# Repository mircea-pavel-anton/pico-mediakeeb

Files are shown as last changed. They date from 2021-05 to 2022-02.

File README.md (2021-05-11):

# pico-mediakeeb

A small multimedia macro-pad implemented on top of the RP2040 based Raspberry pi Pico.

---

## Getting Started

The basic steps to get this up and running are:

- Set up your Raspberry Pi Pico
- Order the PCB from your PCB printing service of choice
- Solder all the components to the PCB
- 3D print a case
- Assemble it all together

### Setting up your Pi

Setting up the Raspberry Pi Pico to function as the brains of this operation is a realtively simple 2-step task.

First things first. We need to flash our Pi with the latest CircuitPython uf2 file so that we can use micropython to program it and gain access to useful adafruit libraries.

You can find the latest CircuitPython.uf2 file as well as a flashing guide [here](https://learn.adafruit.com/getting-started-with-raspberry-pi-pico-circuitpython/circuitpython)

Once you flashed your pico, it should unmount by itself and then remount as a storage device called `CIRCUITPYTHON`. That means you succesfully flashed your pi and are ready to continue.  

Next, we need to download or clone this repo, and copy over the contents of `src/` into the mounted `CIRCUITPYTHON` volume, so thy pi can run it. Once you copied everything over, the pi should start running the code. You can tell whether or not it is working by the onboard LED. Once the program starts running, it should turn on. If it doesn't, try unplugging and replugging your pico.

### Printing your own PCB

| PCB Front | PCB Back |
| :---: | :---: |
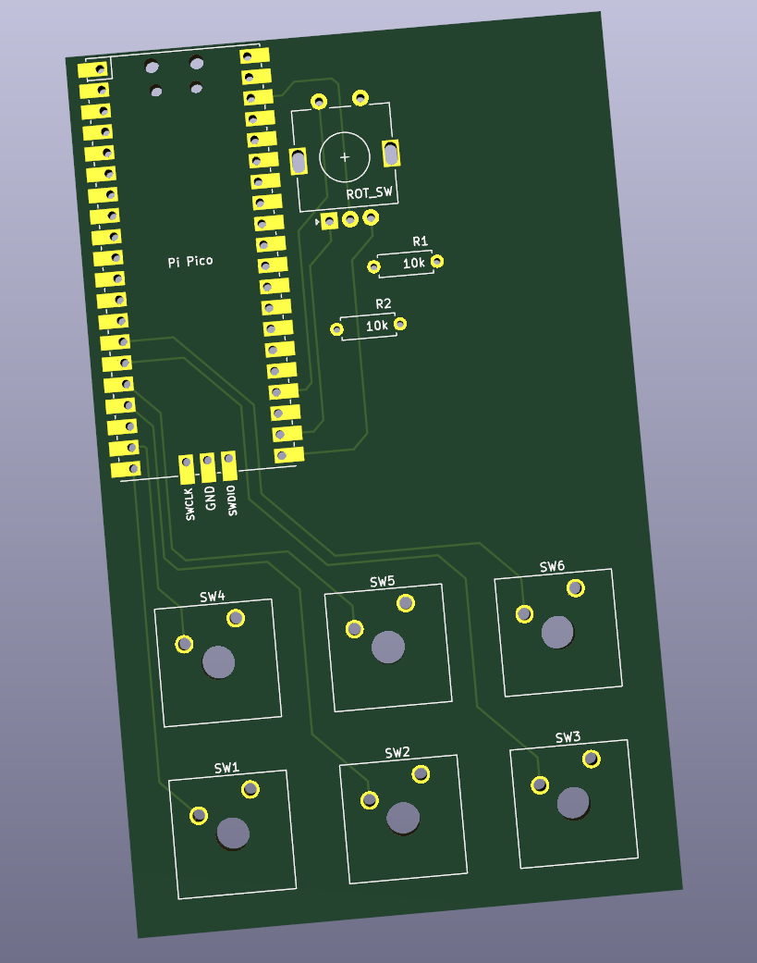
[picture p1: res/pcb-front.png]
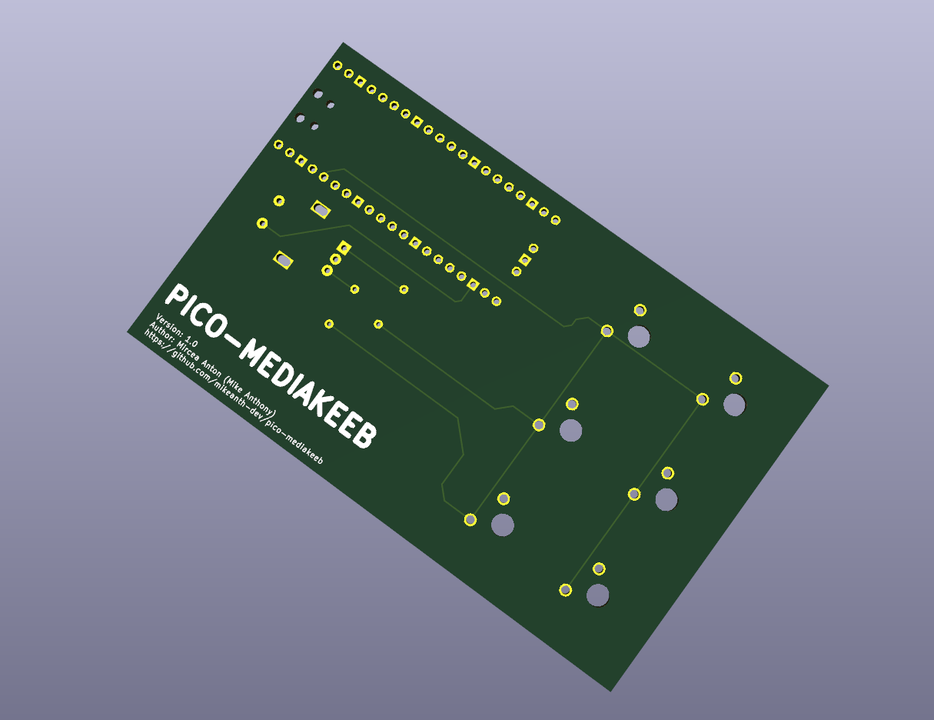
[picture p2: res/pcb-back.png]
|  |  |

In the `pcb/` directory of this repo, you can find a KiCAD project that contains the circuit schematic (in case you want to handwire everything) and a PCB design (in case you want to print your own board). You should open the project and generate the gerber files, or just take the pre-generated ones from `pcb/gerber` and send them to your preffered PCB printing service. I personally used JLC PCB.

### Soldering the components to the PCB

The components you need for this project are the following:

- A raspberry pi Pico
- 2 10k ohm resistors
- a rotary encoder with a switch
- 6 cherry-style keyswitches

All the part names are printed onto the PCB, so you should have no issues in finding out what to solder where.

### 3D printing a case

TODO ...

### Assemble it all together

TODO ...

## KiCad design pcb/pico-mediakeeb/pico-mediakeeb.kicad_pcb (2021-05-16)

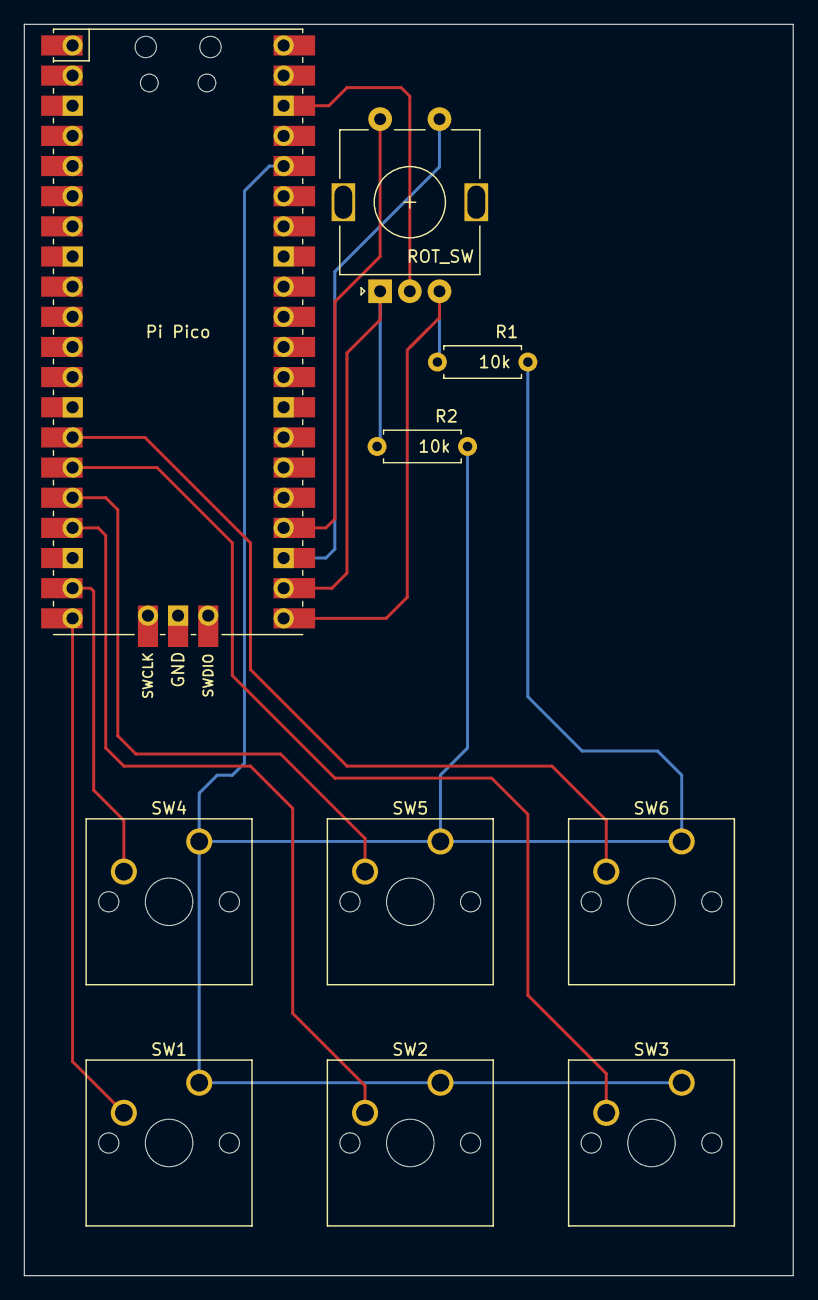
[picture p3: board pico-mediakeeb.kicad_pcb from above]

Board: 2 copper layers, 64.8 x 105.4 mm, 10 parts (0 on the bottom side), 12 nets.

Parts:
Pi Pico: RPi_Pico_SMD_TH
R1, R2: 10k; R_Axial_DIN0207_L6.3mm_D2.5mm_P7.62mm_Horizontal
ROT_SW: Rotary_Encoder_Switch; RotaryEncoder_Alps_EC11E-Switch_Vertical_H20mm
SW1: btn_prev; SW_Cherry_MX_1.00u_PCB
SW2: btn_play_pause; SW_Cherry_MX_1.00u_PCB
SW3: btn_next; SW_Cherry_MX_1.00u_PCB
SW4: btn_macro_1; SW_Cherry_MX_1.00u_PCB
SW5: btn_macro_2; SW_Cherry_MX_1.00u_PCB
SW6: btn_macro_3; SW_Cherry_MX_1.00u_PCB

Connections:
unnamed: Pi Pico.36, R1.1, R2.1, SW1.1, SW2.1, SW3.1, SW4.1, SW5.1, SW6.1
unnamed: Pi Pico.21, R1.2, ROT_SW.B
unnamed: Pi Pico.22, R2.2, ROT_SW.A
unnamed: Pi Pico.20, SW1.2
unnamed: Pi Pico.17, SW2.2
unnamed: Pi Pico.15, SW3.2
unnamed: Pi Pico.19, SW4.2
unnamed: Pi Pico.16, SW5.2
unnamed: Pi Pico.14, SW6.2
unnamed: Pi Pico.38, ROT_SW.C
unnamed: Pi Pico.23, ROT_SW.S1
unnamed: Pi Pico.24, ROT_SW.S2

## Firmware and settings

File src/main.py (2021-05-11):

# ------------ Imports ------------
import board
from button import Button
from led import Led
from encoder import Encoder
from functions import *

# ------------ Track control Buttons ------------
# Previous Track
btn_prev = Button( board.GP15 )
btn_prev.setOnPressCallback( prev_track )

# Play/Pause
btn_plpa = Button( board.GP13 )
btn_plpa.setOnPressCallback( play_pause )

# Next Track
btn_next = Button( board.GP11 )
btn_next.setOnPressCallback( next_track )

# ------------ Colume control ------------
# Volume encoder
vol_encoder = Encoder( board.GP17, board.GP16, board.GP18 )
vol_encoder.setOnRotateCwCallback( volume_up )
vol_encoder.setOnRotateCcwCallback( volume_down )
vol_encoder.setOnPressCallback( mute_toggle )
vol_encoder.setOnReleaseCallback( mute_toggle )

# ------------ Extra Function Keys ------------
# Macro Button #1
btn_mac1 = Button( board.GP14 )
btn_mac1.setOnPressCallback( macro1 )

# Macro Button #2
btn_mac2 = Button( board.GP12 )
btn_mac1.setOnPressCallback( macro1 )

# Macro Button #3
btn_mac3 = Button( board.GP10 )
btn_mac1.setOnPressCallback( macro1 )

# ------------ Status LED ------------
led = Led( board.LED )


led.on()
while True:
    # Track Control Buttons
    btn_prev.onClick()
    btn_plpa.onClick()
    btn_next.onClick()
    
    # Extra Function Keys
    btn_mac1.onClick()
    btn_mac2.onClick()
    btn_mac3.onClick()


    # Volume Control
    vol_encoder.onRotate()
    vol_encoder.onClick()
led.off()

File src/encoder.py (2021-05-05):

import digitalio
from button import Button

class Encoder:
    data = None
    data_old = None
    clock = None
    clock_old = None
    
    onRotateCwCallback = None
    onRotateCcwCallback = None
    
    button = None
    
    def __init__(self, clk_pin, dt_pin, sw_pin):
        self.data = digitalio.DigitalInOut( dt_pin)
        self.data.direction = digitalio.Direction.INPUT
        self.data_old = False

        self.clock = digitalio.DigitalInOut( clk_pin )
        self.clock.direction = digitalio.Direction.INPUT
        self.clock_old = False
        
        self.button = Button( sw_pin, digitalio.Pull.UP )

    def onRotate(self):
        clock_now = self.clock.value
        data_now = self.data.value

        if clock_now != self.clock_old:
            data_now = clock_now ^ data_now
            if data_now:
                if self.onRotateCwCallback is not None:
                    self.onRotateCwCallback()
            else:
                if self.onRotateCcwCallback is not None:
                    self.onRotateCcwCallback()
        self.clock_old = clock_now

    def onClick(self):
        self.button.onClick()

    def setOnRotateCwCallback(self, method):
        self.onRotateCwCallback = method
    
    def setOnRotateCcwCallback(self, method):
        self.onRotateCcwCallback = method
        
    def setOnPressCallback(self, method):
        self.button.onPressCallback = method

    def setOnReleaseCallback(self, method):
        self.button.onReleaseCallback = method

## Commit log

2021-05-04 Rename the pico board to `pico-mediakeeb`
2021-05-04 Add 3 more macro buttons
2021-05-05 Create custom class for buttons
2021-05-05 Create custom class for rotary encoders
2021-05-05 Create custom class for leds
2021-05-05 Create kicad Project
    [pico-mediakeeb.kicad_pcb, pico-mediakeeb.sch]
2021-05-05 Change button pins
2021-05-05 change pin order
2021-05-05 Add circuit schematic
2021-05-05 Make labels more readable
    [pico-mediakeeb.sch]
2021-05-05 Update schematic to use generic rotary encoder
    [pico-mediakeeb.sch]
2021-05-05 Remove unused lib
    [pico-mediakeeb.kicad_pcb]
2021-05-05 Update schematic
    [pico-mediakeeb.sch]
2021-05-05 Auto generate PCB
    [pico-mediakeeb.kicad_pcb]
2021-05-07 Update pcb design
2021-05-11 Reorder buttons to make more sense for the pcb design
    [pico-mediakeeb.sch]
2021-05-11 Implement pcb design v1
    [pico-mediakeeb.kicad_pcb]
2021-05-11 Update code to reflect button pin changes
2021-05-11 Upload PCB screenshots
2021-05-11 Add pcb screenshots
2021-05-11 Add gerber files
    [pico-mediakeeb-B_Cu.gbl, pico-mediakeeb-B_Mask.gbs, pico-mediakeeb-B_SilkS.gbo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]
2021-05-16 Update pcb traces and add JLC order number placeholder
    [pico-mediakeeb.kicad_pcb]
2021-05-16 Update gerber files
    [pico-mediakeeb-B_Cu.gbr, pico-mediakeeb-B_Mask.gbr, pico-mediakeeb-B_Paste.gbr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]
2022-02-01 [ImgBot] Optimize images (#1)
    *Total -- 198.81kb -> 119.53kb (39.87%)
    /res/pcb-back.png -- 92.08kb -> 51.34kb (44.24%)
    /res/pcb-front.png -- 106.73kb -> 68.19kb (36.1%)

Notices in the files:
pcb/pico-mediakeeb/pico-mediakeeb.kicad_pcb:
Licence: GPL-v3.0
